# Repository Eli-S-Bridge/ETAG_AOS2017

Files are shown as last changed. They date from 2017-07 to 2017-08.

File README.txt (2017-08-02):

ETAG RFID reader Version1
(Distrubted at the American Ornithological Society Meeting, Lansing, MI, August 2017.

This repository contains:
  1) Eagle design files for the circuit board
  2) A board reference for using the Arduino app with the circuit board.
  3) Arduino code to install on the circuit board

SOFTWARE:

See the setup manual.

HARDWARE:

You can power the board from your USB port or use a 5V battery. 6V batteries seem to work OK too. We’ve tested 4AA batteries in series (which give ~6V). You can power the reader from the USB port or the push-in connectors. Check the + and - labels on the board before connecting the battery leads. The large switch on the circuit board alternates between power sources. If you have both USB and a battery connected, you will not really be able to turn the device off (but you can always use the reset button).

Antenna coils should have inductance of approximately 1.3 milliHenries. You can make the coils yourself by wrapping magnet wire around a form and measuring the inductance until you get it right. Don’t make them bigger than 15cm in diameter or they won’t work very well. You can also buy 1.25mH antennas that work pretty well here:

https://store.qkits.com/rfid/125khz-antenna-for-rfid-controllers-51-5mm.html

Tags need to work at 125kHz and follow the EM4100 communication protocol. Biomark tags generally follow the ISO11784/5 communication protocol will not work. Our favorite tag suppliers are www.cyntag.com (for PITtag style tags) and ibtechnology.co.uk (for RFID leg bands - look for “avian products”)

OTHER RESOURCES:

YouTube video demonstration: https://www.youtube.com/watch?v=-Nv7rSirzx8

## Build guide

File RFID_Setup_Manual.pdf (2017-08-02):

# Table of Contents

1 Introduction | 1
2 Software Installation | 2

1

# Chapter 1

# Introduction

This is the ETAG RFID reader Version1 (Distrubted at the American Ornithological Society Meeting, Lansing, MI, August 2017) guide to set up the software and hardware. This guide will give directions to obtain the Eagle design files for the circuit board, Arduino software, Arduino circuit board code, and an introduction to upload the code to the board for use.

1

# Chapter 2

# Software Installation

This section will direct to download the Ardunio software, RFID code, and RFID data files that are necessary to make the RFID board operational and enable changes to RFID code. This guide will begin by obtaining and installing the Ardunio software then downloading RFID code and data files. The RFID code and data files must be placed in certain Arduno’s directory, this will be further explained in detail.

## 2.1 Ardunio Software

First, go to the Ardunio website to obtain the installer by using the following

link as provided, https://www.arduino.cc/en/Main/Software. The website should appears as Figure 2.1. Click on ”Windows Installer” that is located on the mid-right side of the website. This will redirect you to the next page,

2

Ardunio’s donation page, click ”JUST DOWNLOAD” as shown in Figure 2.2 to begin downloading the executable file.

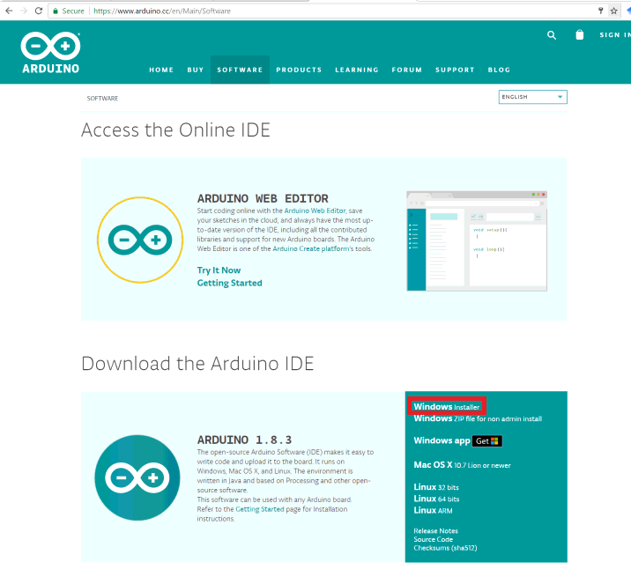
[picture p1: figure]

Figure 2.1: The Arduino Software page to access the correct Ardunino version for your computer. Windows computer should click on ”Windows Installer” to proceeding towards obtaining the Arduino software.

3

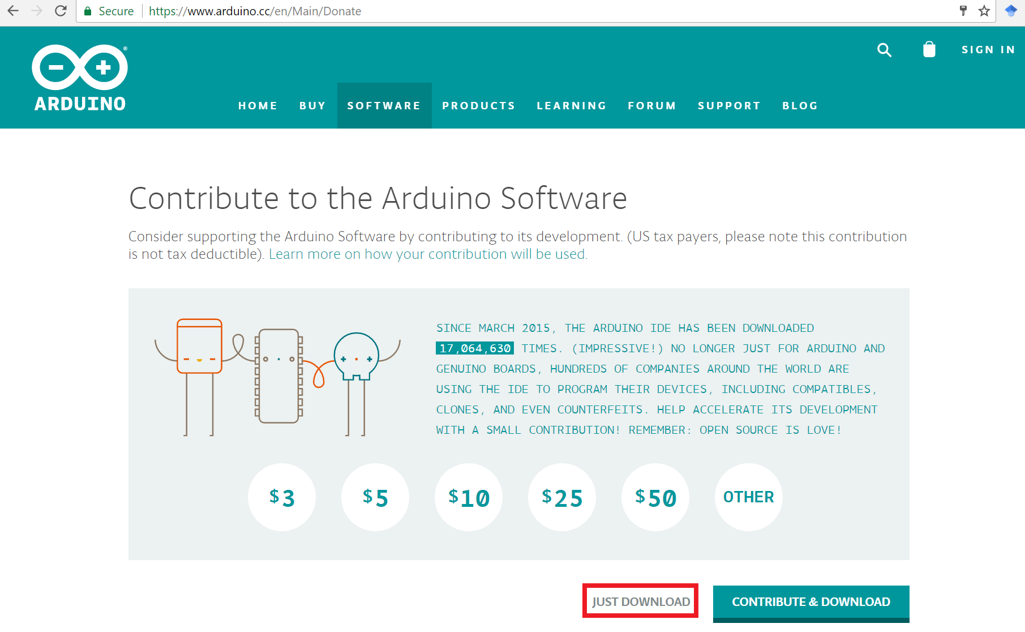
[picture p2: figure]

Figure 2.2: The redirected donation page after clicking ”Windows Installer”. Click on ”JUST DOWNLOAD” to begin downloading the executable file.

4

Locate and double click on the executable file, this will prompt the installer to begin. The initial installer’s title is Arduino Setup: License Agreement window. Read the terms and agreement then click ”I Agree” to begin the installation as shown in Figure 2.3. The installer’s title changes to Arduino Setup: Installation Options, as shown in Figure 2.4, click ”Next”.

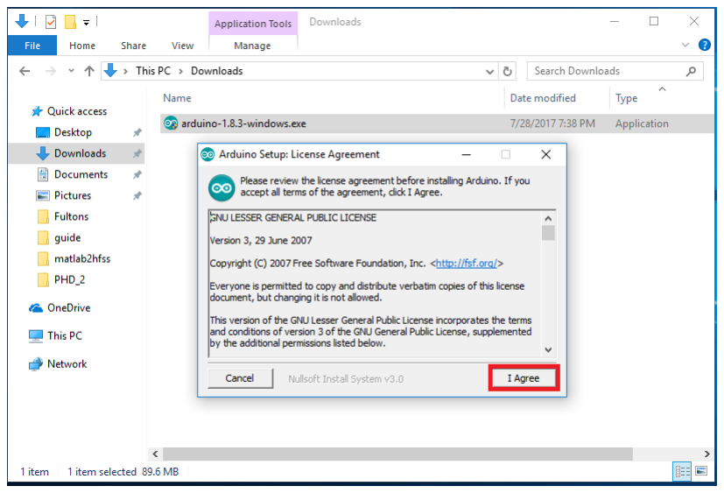
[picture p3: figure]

Figure 2.3: Installer window, displaying the terms and agreements. Click ”I Agree” to continue.

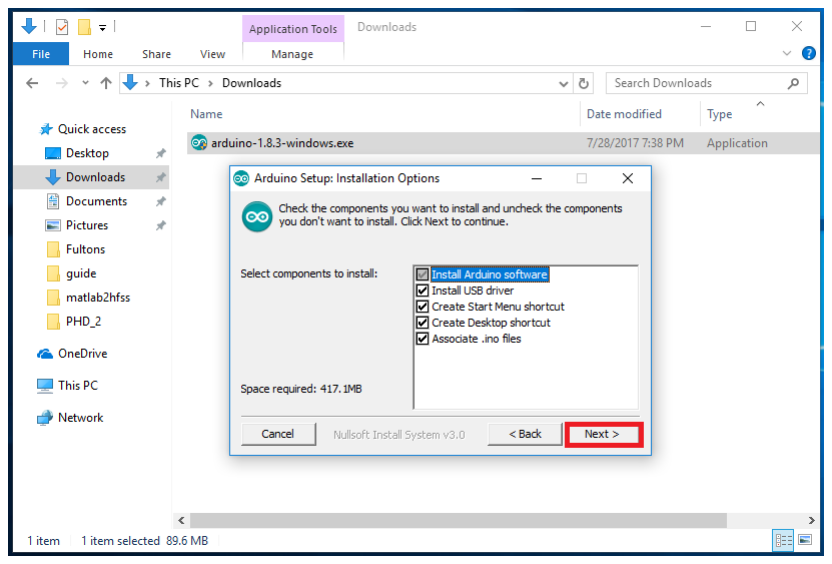
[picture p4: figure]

Figure 2.4: Installer options, click ”Next” to continue.

5

The installer’s title is change to Arduino Setup: Installation Folder, the Default location to install the software will be automatically set. Install location can be changed by clicking ”Browse...”. Click ”Install” as shown in Figure 2.5 to begin but highly recommend to default location. The window will display a progress bar, once completed it state ”Completed” as shown in Figure 2.6, click ”Close”.

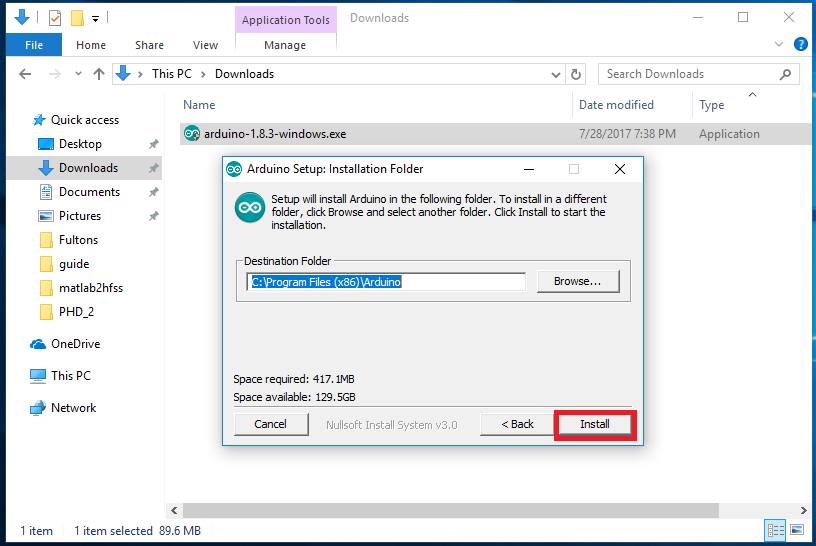
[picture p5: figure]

Figure 2.5: Installer allowing the user to choose destination location for software. Click ”Install” to continue.

6

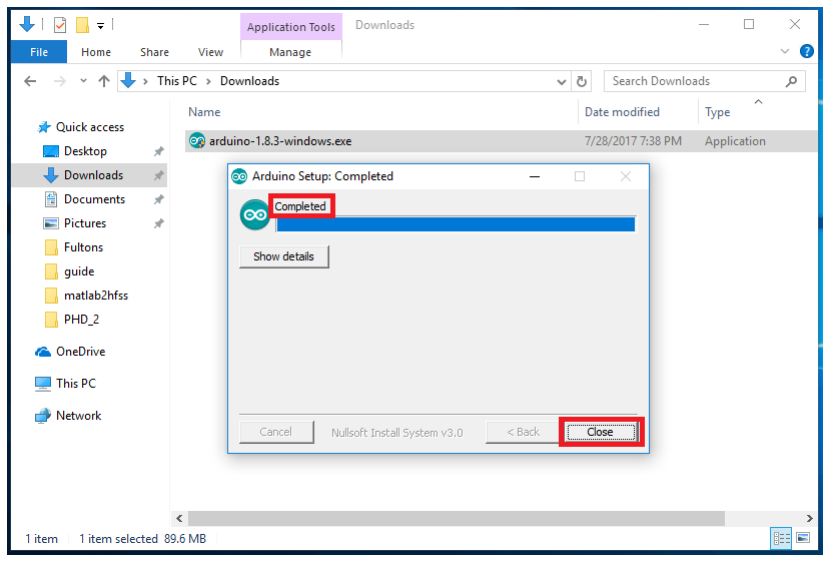
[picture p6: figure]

Figure 2.6: Installer displaying an example of when the installer is completed. click ”Close” to finish.

Accessing the software, click the Windows button on the keyboard prompting the start menu, search ”Arduino”, click on Arduino to run the software. The Arduino software should be successfully installed and running, it will appear as in Figure 2.7

7

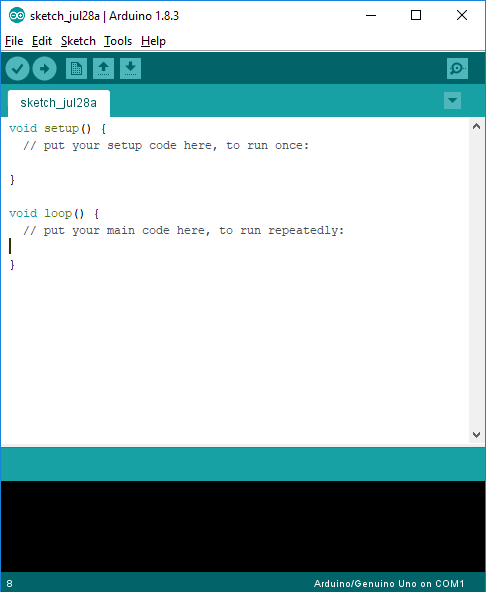
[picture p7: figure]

Figure 2.7: a

8

Next connect your Arduino board to the computer via USB cable, as shown in Figure 2.8. Once the Arduino board is connected to your computer use the switch on the lower right side near the USB port to turn it on, once on the yellow LED light to the side of the switch will light as shown in Figure 2.8(b).

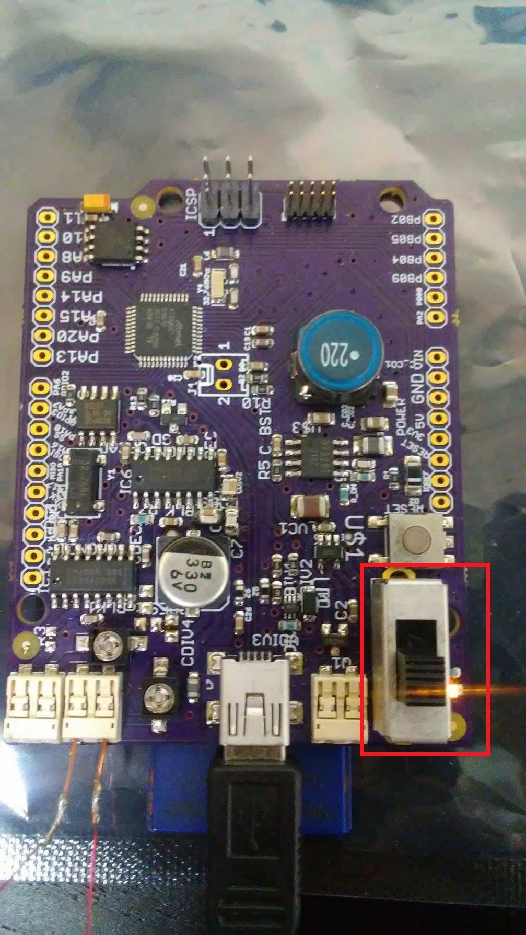
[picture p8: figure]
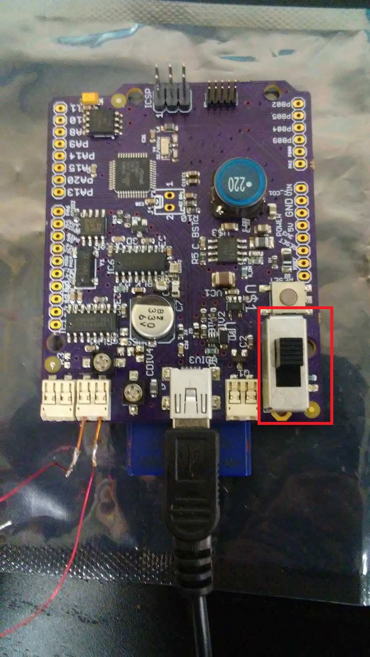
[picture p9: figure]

(a) (b)
Figure 2.8: Use the switch on the bottom right of the Ardunio board near the USB port to turn on the board off and on. A yellow LED to the side of the switch will indicate if the ON or OFF. (a) Yellow LED OFF indicating that Arduino is OFF
(b) Yellow LED ON indicating that Arduino is ON.

9

Once the Arduino board turns on the Arduino software will prompt for updates in the lower left corner as shown in Figure 2.9. Click on this prompt, a new window will open as shown in Figure 2.10. Click on ”Install”, the software will automatically install the files required and will proceed as shown in Figure 2.11, and wait a moment until the window is completed as shown in Figure 2.12.

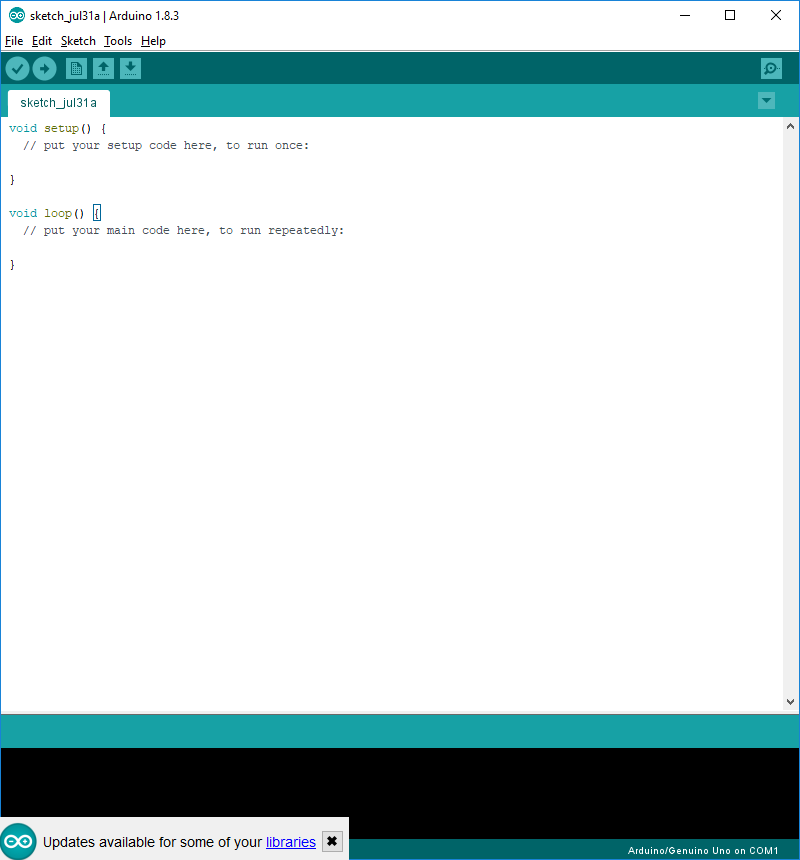
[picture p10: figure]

Figure 2.9: Arduino software prompting for updates after the Arduino board has been turned when connected to the computer. Click on the prompt to install the required updates

10

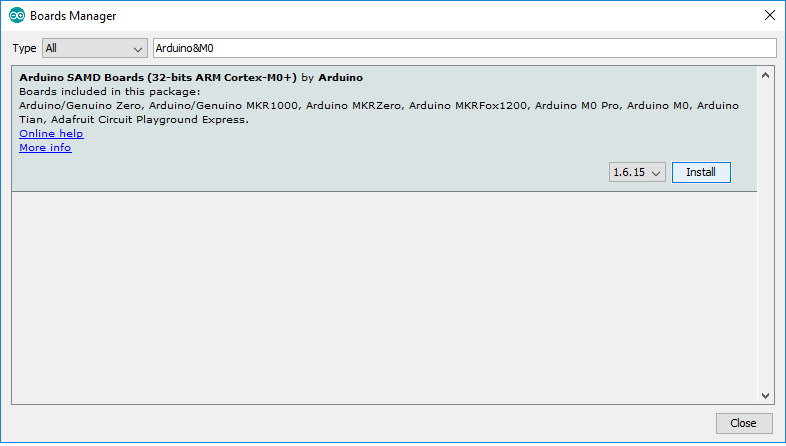
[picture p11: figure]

Figure 2.10: Window prompt to install the required files for Arduino board. Click on the ”Install” button to install required files.

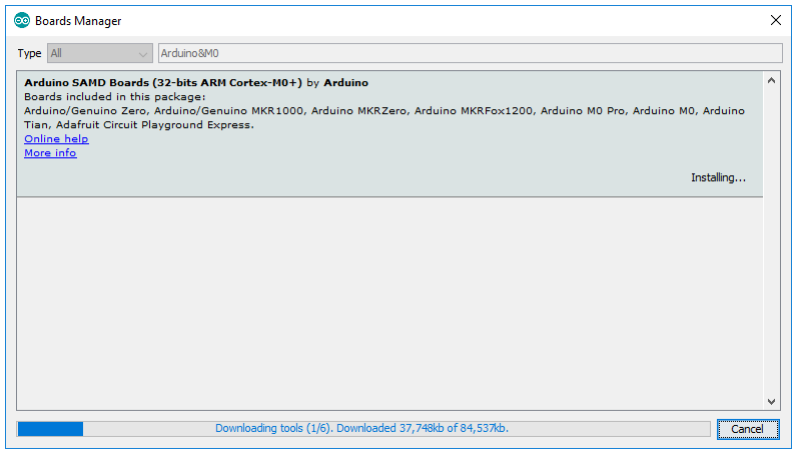
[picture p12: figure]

Figure 2.11: The window prompt in progress during installation. Allow a few moments until it is done installing files.

11

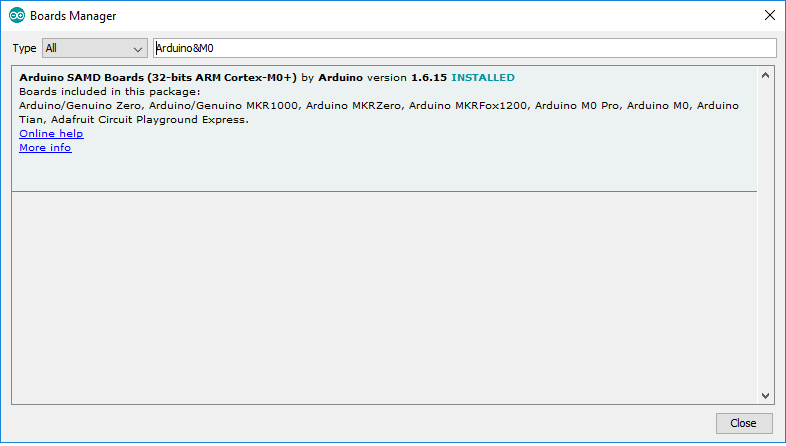
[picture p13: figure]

Figure 2.12: The Arduino software has successfully installed the required files. Click on ”Close”.

Once installation is completed close all Arduino software to prepare for the procedures steps. In the next section there will be directions to obtain our code and files required in utilizing the RFID board.

12

## 2.2 Circuit Board Code and Files

The circuit board code and files can be downloaded from the following url link,

https://github.com/Eli-S-Bridge/ETAG_AOS2017. The web page should appear as in Figure 2.13. Click on ”Clone or download”, a menu box will appear then click ”Download ZIP”. Download the Zip file onto your computer. Once download is complete, locate the Zip file, right click, a window prompt should appear similar to Figure 2.14, and unzip(extract) the files onto your computer.

13

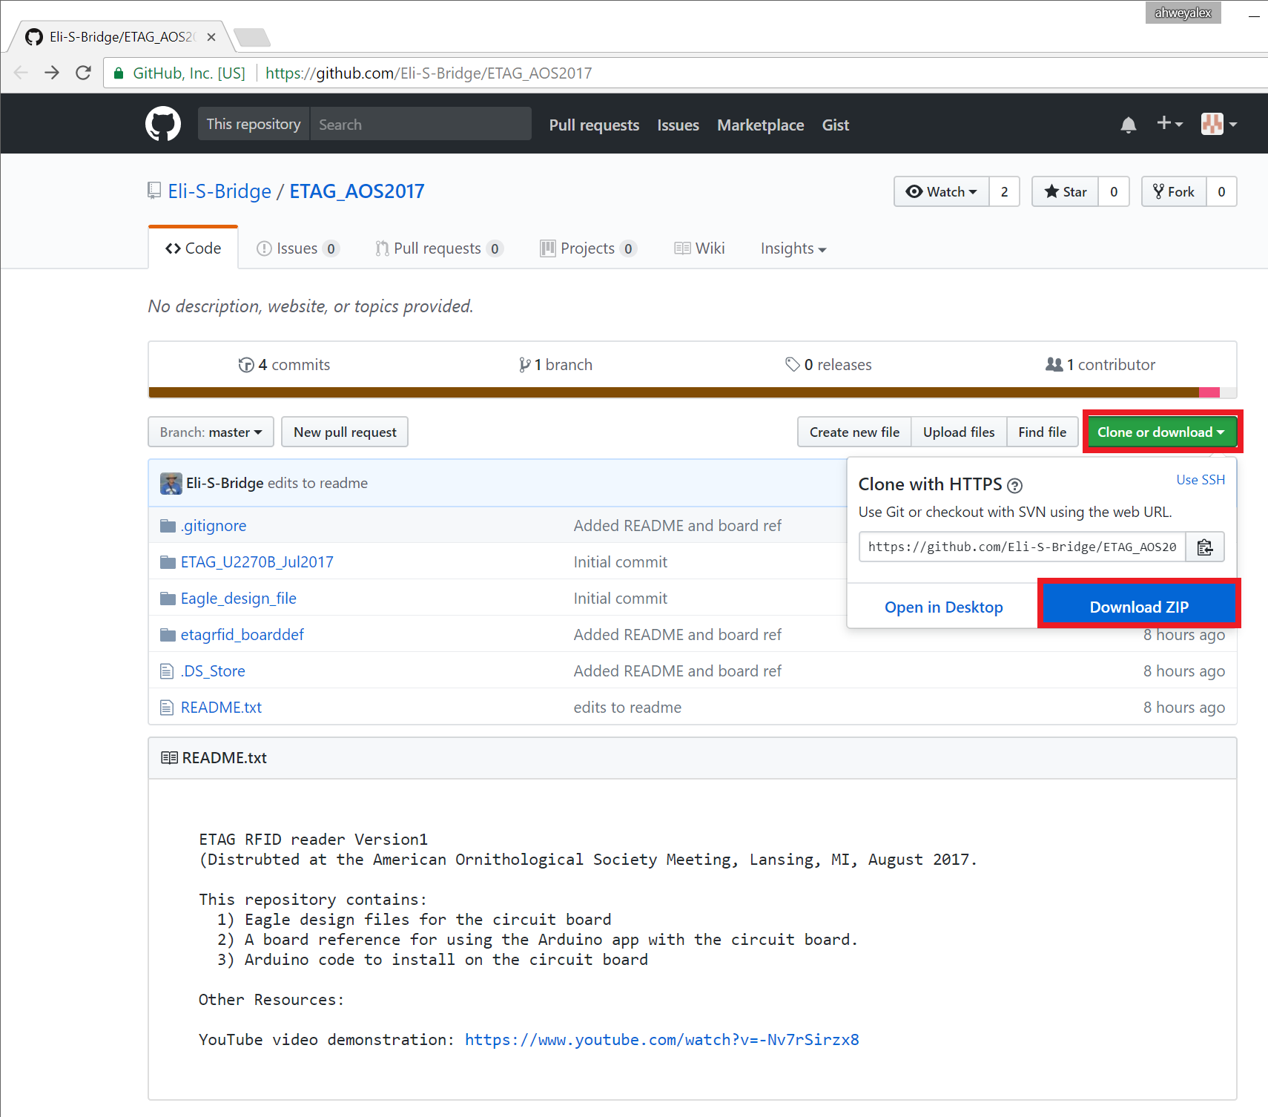
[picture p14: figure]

Figure 2.13: The GitHub web page to download the circuit board code and files. Click on ”Clone or download” then click on ”Download ZIP”.

14

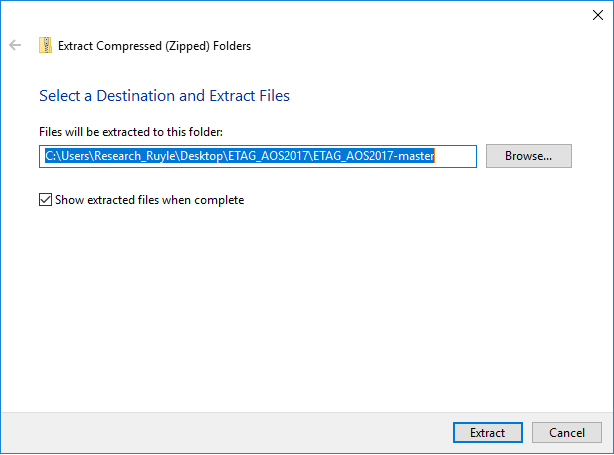
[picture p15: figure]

Figure 2.14: Right click on the zip file that was

15

Open the folder that has just been extracted(unzipped) until you reached a folder that shows the same contents as in Figure 2.15. There are three items(the ”ETAG U2270B” folder,”etagfid” folder, and board.txt file) in this folder that need
to be relocated. Open the folder ”etagfid boarddef” and copy ”board.tx” to

C:\Users\USERNAME\AppData\Local\Arduino15\packages\arduino\ hardware\samd\1.6.15 this will prompt a window, click ”Replace the file
in the destination”, as shown in Figure 2.16. The USERNAME refers to your computer’s user name.

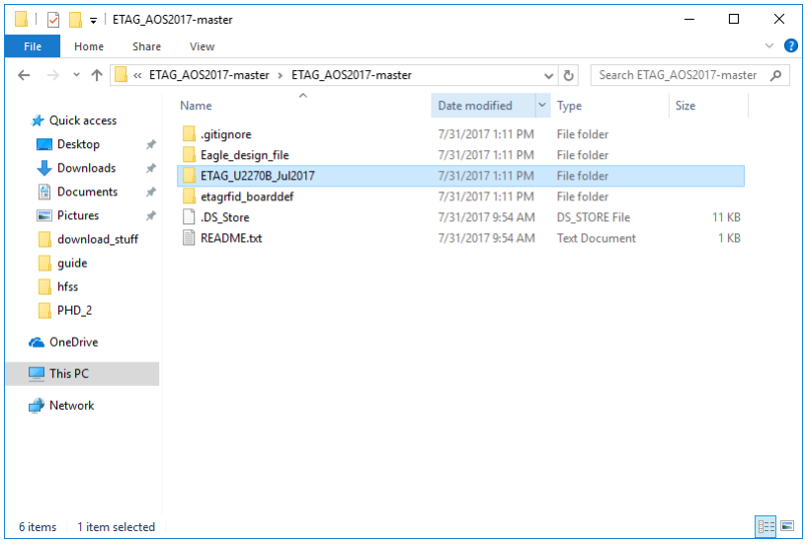
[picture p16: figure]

Figure 2.15: The contents of the unzipped folder.

16

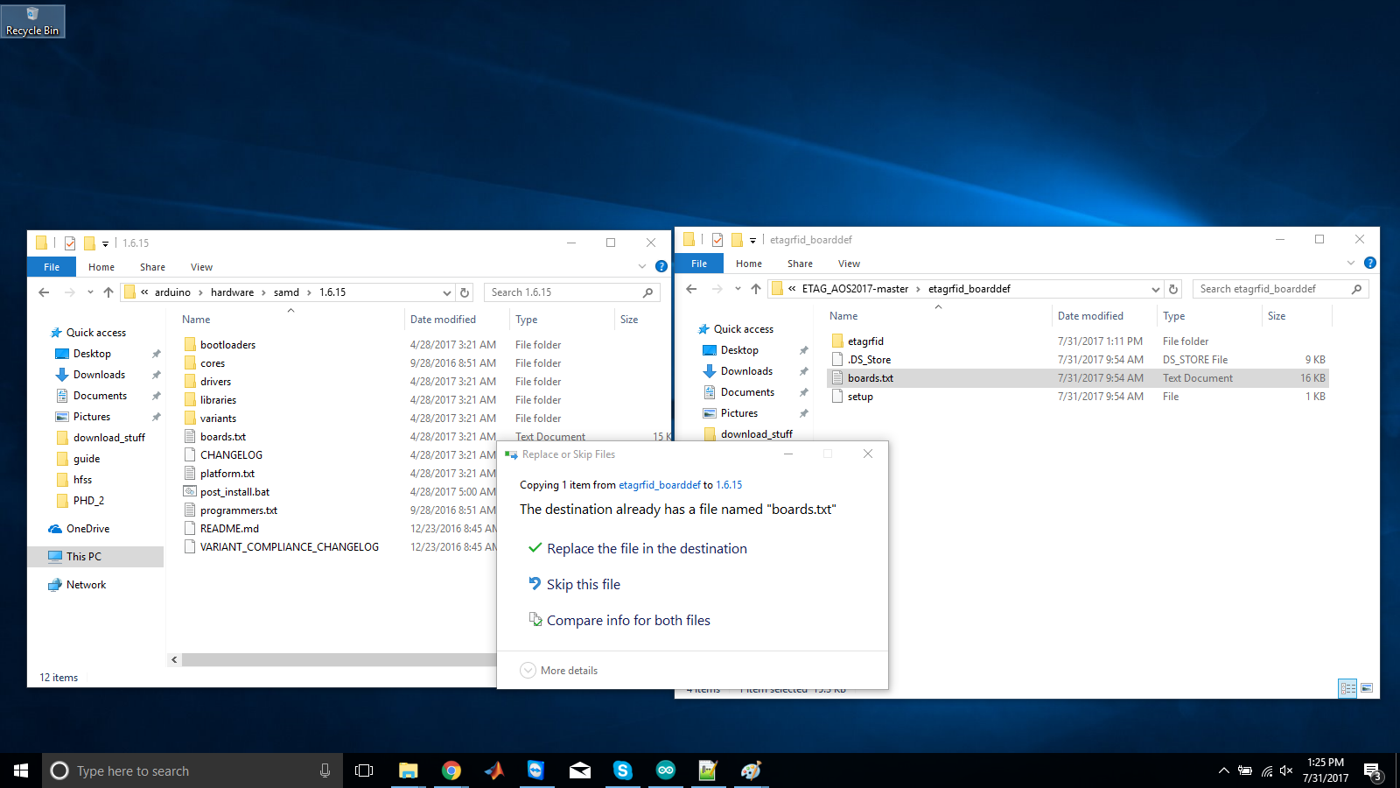
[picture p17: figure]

Figure 2.16: Copying the ”board.txt” file from the unzipped folder into to the path. Click ”Replace the file in the destination”.

17

Next, copy the ”etagfid” folder to the following path,

C:\Users\USERNAME\AppData\Local\Arduino15\packages\arduino\

hardware\samd\1.6.15\variants/ as shown in Figure 2.17.

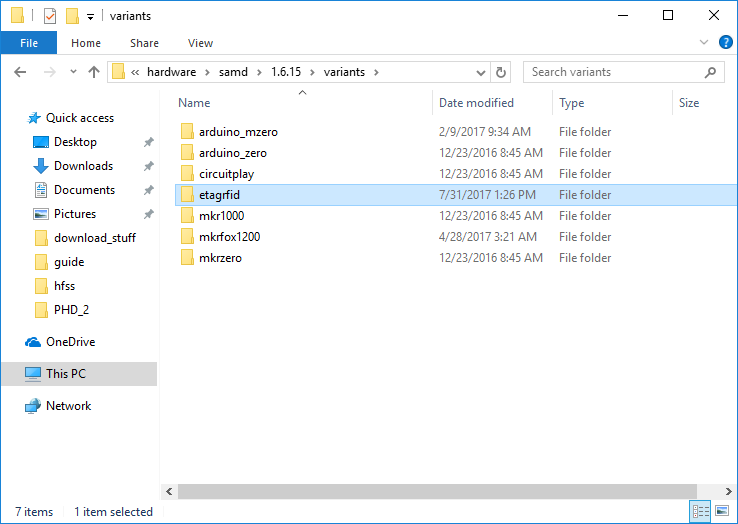
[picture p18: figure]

Figure 2.17

18

Finally, copy the ”ETAG U2270B Jul2017” folder to your Arduino folder located in your Documents folder. This will allow Arduino software easy access to the code.
Open the folder ”ETAG U2270B Jul2017” in your documents, click on ”ETAG U2270B Jul2017.ino” file this will open it in the Arduino software. Then click ”Tools”, scroll down to ”Broad:BOARDNAME”, scroll down and click ”ETAG RFID”. This will ensure compiler to take into account the custom board parameters.
Connect your Arduino board to your computer, turn the board via switch, click on the check mark symbol to verify(compile) the code as shown in Figure 2.18. Once the it completes verifying it will appear as shown Figure 2.19. Then click on the arrow symbol to upload the code into the board. Turn the board off (insert an SD card into the board, if it does not have one) and back on. Next, click on ”Tools”, scroll down to ”Port” and choose ”COM XX”. Finally, Click ”Tools” then scroll down and click on ”Serial Monitor” to prompt the console. Near the tag to the antenna connected to the board to read the tag’s information. The information will be displayed on the console and written onto the SD card.

19

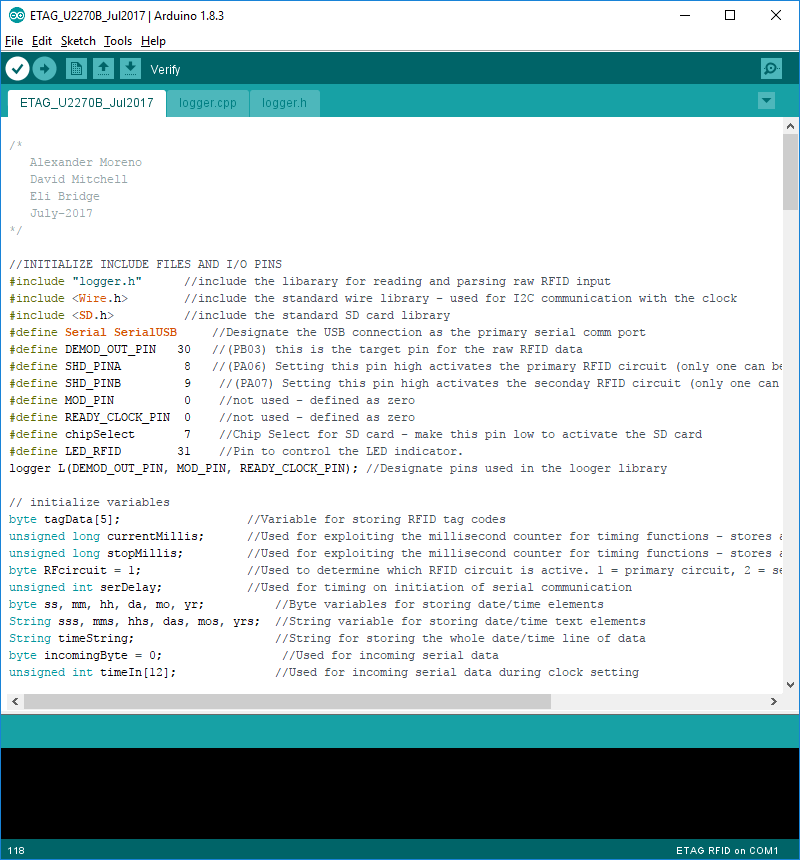
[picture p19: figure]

Figure 2.18: Board code to the RFID.

20

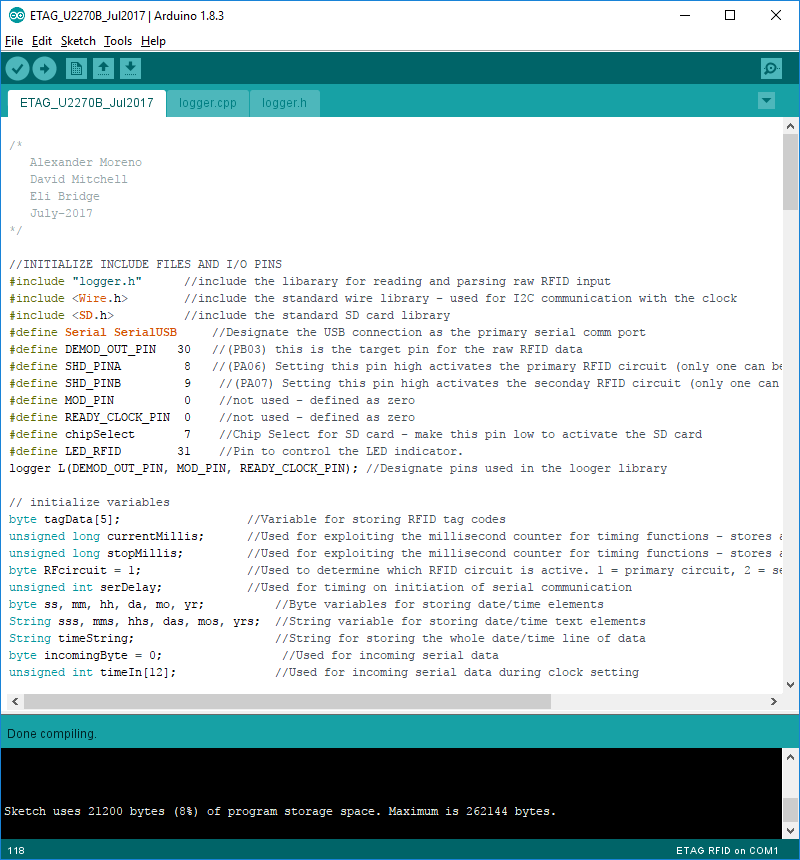
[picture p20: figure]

Figure 2.19: Board code has completed being complied ready to be uploaded to the board.

21

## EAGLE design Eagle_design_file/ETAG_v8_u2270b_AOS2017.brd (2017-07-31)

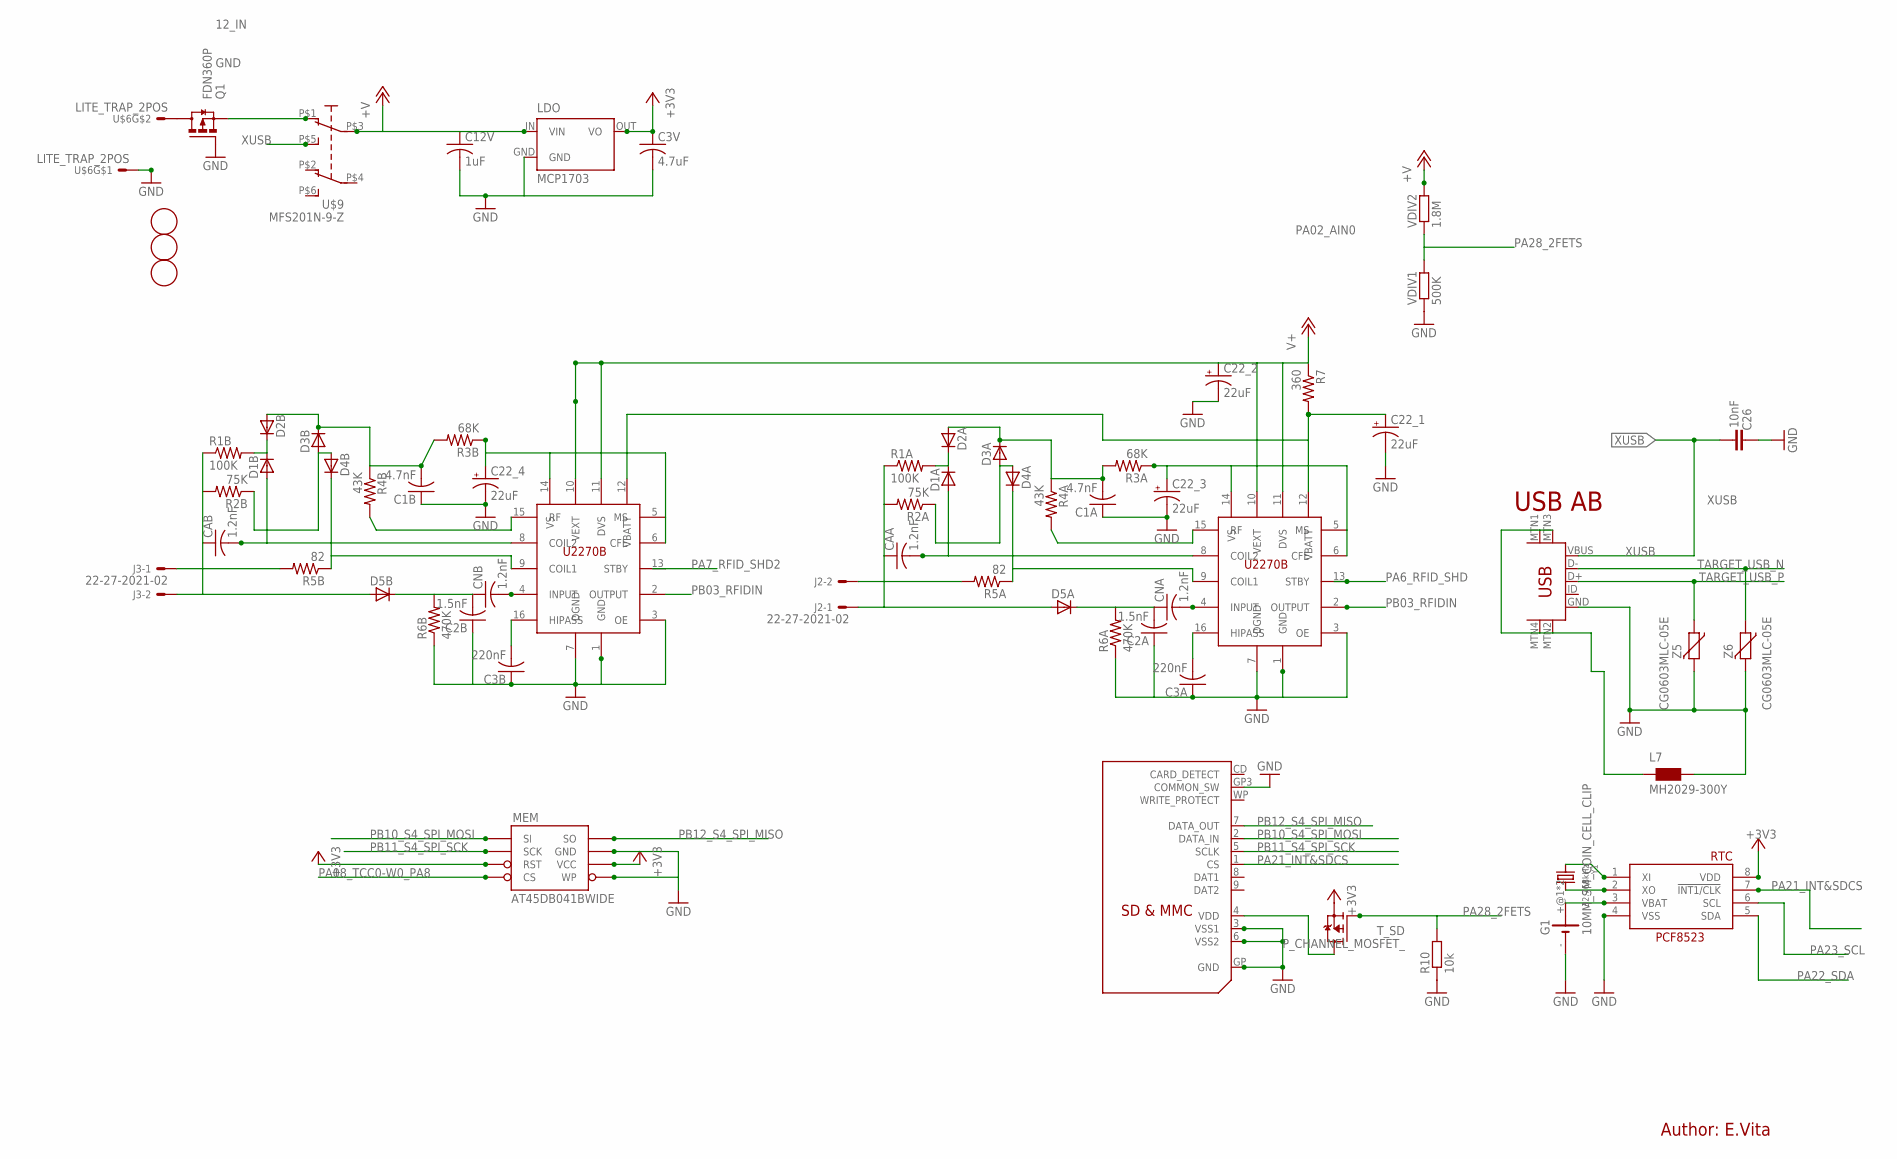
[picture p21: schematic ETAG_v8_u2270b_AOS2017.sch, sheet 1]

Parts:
C1A, C1B: 4.7nF; C0603-ROUND
C2A, C2B: 1.5nF; C0805
C3A, C3B: 220nF; C0603-ROUND
C3V: 4.7uF; C0805
C12V: 1uF; C0805
C22_1, C22_2, C22_3, C22_4: 22uF; 153CLV-0505
C26: 10nF; C0603-ROUND
CAA: 1.2nF; C0805
CAB: 1.2nF; C0805
CNA: 1.2nF; C0805
CNB: 1.2nF; C0805
D1A, D1B, D2A, D2B, D3A, D3B, D4A, D4B, D5A, D5B: D-GLASS_MELF; SOT-23_2PAD
FD1, FD2, FD3: FIDUCIALMOUNT; FIDUCIA-MOUNT
G1: 10MM_SM_COIN_CELL_CLIP
J2, J3: 22-27-2021-02; 6410-02
L7: MH2029-300Y; 0805
LDO: MCP1703; SOT89
MEM: AT45DB041BWIDE; SO08WIDE
Q1: FDN360P; SUPER-SOT3
R1A, R1B: 100K; C0603-ROUND
R2A, R2B: 75K; C0603-ROUND
R3A, R3B: 68K; C0603-ROUND
R4A, R4B: 43K; C0603-ROUND
R5A, R5B: 82; C0603-ROUND
R6A, R6B: 470K; C0603-ROUND
R7: 360; C0603-ROUND
R10: 10k; R0603-ROUND
RF_A: U2270B; SO16
RF_B: U2270B; SO16
RTC: RTC_PCF8523T; SOIC8_150MIL
T_SD: P_CHANNEL_MOSFET_; SOT23
U$4: SDMMC06132; 06132
U$6: LITE_TRAP_2POS; LITE_TRAP_MINI
U$9: MFS201N-9-Z
USB: USB-MINIB-5PIN; USB-MINIB
VDIV1: 500K; R0603-ROUND
VDIV2: 1.8M; R0603-ROUND
Y1: 32.768kHz; CRYSTAL_8X3.8
Z5, Z6: CG0603MLC-05E; CT/CN0603

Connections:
2GND: L7.1, USB.MTN1 (MTN2), USB.MTN2 (MTN3), USB.MTN3 (MTN1), USB.MTN4
12_IN: Q1.3 (D), U$6.P$3, U$6.P$4
+3V3: C3V.1, LDO.OUT (VO), MEM.3 (RST), MEM.6 (VCC), RTC.8 (VDD), T_SD.2 (S); also elsewhere on the board
GND: C1A.1, C1B.1, C2A.1, C2B.1, C3A.1, C3B.1, C3V.2, C12V.2, C22_1.-, C22_2.-, C22_3.-, C22_4.-, C26.2, G1.-, L7.2, LDO.GND, MEM.5 (WP), MEM.7 (GND), Q1.1 (G), R6A.1, R6B.1, R10.1, RF_A.1 (GND), RF_A.3 (OE), RF_A.7 (DGND), RF_B.1 (GND), RF_B.3 (OE), RF_B.7 (DGND), RTC.4 (VSS), U$4.3 (VSS1), U$4.6 (VSS2), U$4.GP (GND), U$4.GP3 (COMMON_SW), U$6.P$1, U$6.P$2, USB.GND, VDIV1.1, Z5.2, Z6.2; also elsewhere on the board
unnamed: RTC.2 (XO), Y1.P$4 (2)
unnamed: RTC.1 (XI), Y1.P$1 (1)
unnamed: C22_1.+, R7.2, RF_A.12 (VBATT), RF_B.12 (VBATT)
unnamed: C3A.2, RF_A.16 (HIPASS)
unnamed: CNA.2, RF_A.4 (INPUT)
unnamed: C2A.2, CNA.1, D5A.P$1 (C), R6A.2
unnamed: C1A.2, D2A.P$2 (A), D3A.P$1 (C), R3A.2, R4A.1
unnamed: J2.2, R5A.2
unnamed: J3.1, R5B.2
unnamed: Q1.2 (S), U$9.P$1 (O)
unnamed: D1A.P$1 (C), D2A.P$1 (C), R1A.2
unnamed: C3B.2, RF_B.16 (HIPASS)
unnamed: D3A.P$2 (A), D4A.P$2 (A), R2A.1
unnamed: CNB.2, RF_B.4 (INPUT)
unnamed: C2B.2, CNB.1, D5B.P$1 (C), R6B.2
unnamed: D4B.P$1 (C), R5B.1, RF_B.9 (COIL1)
unnamed: CAB.2, D1B.P$2 (A), RF_B.8 (COIL2)
unnamed: CAB.1, D5B.P$2 (A), J3.2, R1B.1, R2B.2
unnamed: R4B.2, RF_B.15 (RF)
unnamed: C22_4.+, R3B.1, RF_B.5 (MS), RF_B.6 (CFE), RF_B.14 (VS)
unnamed: D1B.P$1 (C), D2B.P$1 (C), R1B.2
unnamed: D3B.P$2 (A), D4B.P$2 (A), R2B.1
unnamed: C1B.2, D2B.P$2 (A), D3B.P$1 (C), R3B.2, R4B.1
unnamed: D4A.P$1 (C), R5A.1, RF_A.9 (COIL1)
unnamed: CAA.2, D1A.P$2 (A), RF_A.8 (COIL2)
unnamed: CAA.1, D5A.P$2 (A), J2.1, R1A.1, R2A.2
unnamed: R4A.2, RF_A.15 (RF)
unnamed: C22_3.+, R3A.1, RF_A.5 (MS), RF_A.6 (CFE), RF_A.14 (VS)
PA02_AIN0: VDIV1.2, VDIV2.1; also elsewhere on the board
PA6_RFID_SHD: RF_A.13 (STBY); also elsewhere on the board
PA7_RFID_SHD2: RF_B.13 (STBY); also elsewhere on the board
PA08_TCC0-W0_PA8: MEM.4 (CS); also elsewhere on the board
PA21_INT&SDCS: RTC.7 (!INT1/CLK), U$4.1 (CS); also elsewhere on the board
PA22_SDA: RTC.5 (SDA); also elsewhere on the board
PA23_SCL: RTC.6 (SCL); also elsewhere on the board
PA28_2FETS: R10.2, T_SD.1 (G); also elsewhere on the board
PB03_RFIDIN: RF_A.2 (OUTPUT), RF_B.2 (OUTPUT); also elsewhere on the board
PB10_S4_SPI_MOSI: MEM.1 (SI), U$4.2 (DATA_IN); also elsewhere on the board
PB11_S4_SPI_SCK: MEM.2 (SCK), U$4.5 (SCLK); also elsewhere on the board
PB12_S4_SPI_MISO: MEM.8 (SO), U$4.7 (DATA_OUT); also elsewhere on the board
TARGET_USB_N: USB.D-, Z6.1; also elsewhere on the board
TARGET_USB_P: USB.D+, Z5.1; also elsewhere on the board
VBAT1: G1.+@1 (+), G1.+@2 (+), RTC.3 (VBAT)
VDD: T_SD.3 (D), U$4.4 (VDD)
V_IN: C12V.1, C22_2.+, LDO.IN (VIN), R7.1, RF_A.10 (VEXT), RF_A.11 (DVS), RF_B.10 (VEXT), RF_B.11 (DVS), U$9.P$3, VDIV2.2; also elsewhere on the board
XUSB: C26.1, U$9.P$5 (S), USB.VBUS

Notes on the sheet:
USB AB
Author: E.Vita

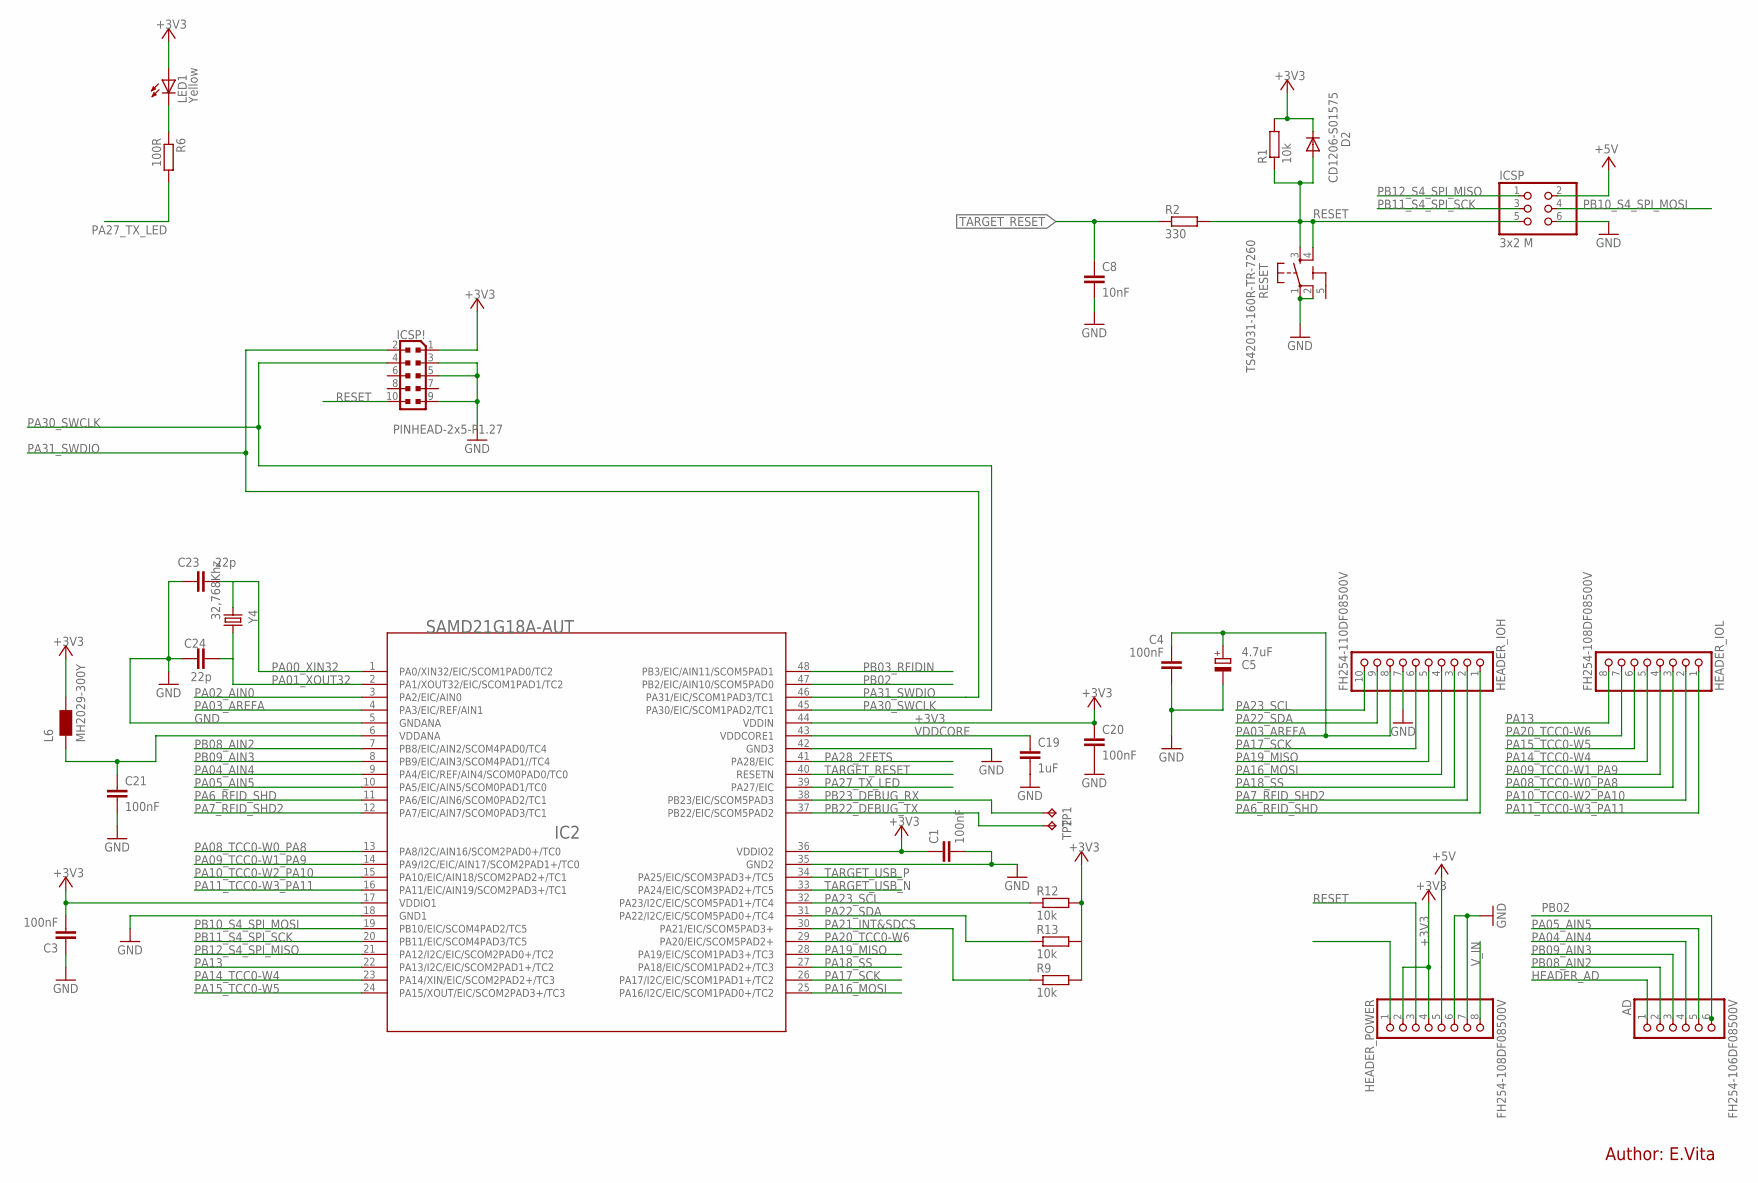
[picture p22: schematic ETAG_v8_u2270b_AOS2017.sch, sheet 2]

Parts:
AD: FH254-106DF08500V; 1X06
C1, C3, C4, C20, C21: 100nF; C0603-ROUND
C5: 4.7uF; SMC_A
C8: 10nF; C0603-ROUND
C19: 1uF; C0603-ROUND
C23, C24: 22p; C0603-ROUND
D2: CD1206-S01575; MINIMELF
HEADER_IOH: FH254-110DF08500V; 1X10
HEADER_IOL: FH254-108DF08500V; 1X08
HEADER_POWER: FH254-108DF08500V; 1X08
IC2: SAMD21G18A-AUT; TQFP48-7X7
ICSP: 3x2 M; 2X03
ICSP!: PINHEAD-2x5-P1.27; PINHEAD_2X05_127
L6: MH2029-300Y; 0805
LED1: Yellow; CHIPLED_0805
R1, R9, R12, R13: 10k; R0603-ROUND
R2: 330; R0603-ROUND
R6: 100R; R0603-ROUND
RESET: TS42031-160R-TR-7260; TS42
TP1, TP2: TPTP15R; TP15R
Y4: 32,768Khz; RESONATOR_EPSON_FC_145

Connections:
5-GND: RESET.5 (5-GND)
+3V3: C1.1, C3.2, C20.1, D2.C, HEADER_POWER.2, HEADER_POWER.4, IC2.17 (VDDIO1), IC2.36 (VDDIO2), IC2.44 (VDDIN), ICSP!.1, L6.2, LED1.A, R1.2, R9.2, R12.2, R13.2; also elsewhere on the board
+5V: HEADER_POWER.5, ICSP.2
GND: C1.2, C3.1, C4.2, C5.-, C8.2, C19.2, C20.2, C21.2, C23.1, C24.1, HEADER_IOH.7, HEADER_POWER.6, HEADER_POWER.7, IC2.5 (GNDANA), IC2.18 (GND1), IC2.35 (GND2), IC2.42 (GND3), ICSP.6, ICSP!.3, ICSP!.5, ICSP!.9, RESET.1, RESET.2; also elsewhere on the board
HEADER_AD: AD.1
unnamed: LED1.C, R6.1
unnamed: C21.1, IC2.6 (VDDANA), L6.1
PA00_XIN32: C23.2, IC2.1 (PA0/XIN32/EIC/SCOM1PAD0/TC2), Y4.P$1 (1)
PA01_XOUT32: C24.2, IC2.2 (PA1/XOUT32/EIC/SCOM1PAD1/TC2), Y4.P$2 (2)
PA02_AIN0: IC2.3 (PA2/EIC/AIN0); also elsewhere on the board
PA03_AREFA: C4.1, C5.+, HEADER_IOH.8, IC2.4 (PA3/EIC/REF/AIN1)
PA04_AIN4: AD.4, IC2.9 (PA4/EIC/REF/AIN4/SCOM0PAD0/TC0)
PA05_AIN5: AD.5, IC2.10 (PA5/EIC/AIN5/SCOM0PAD1/TC0)
PA6_RFID_SHD: HEADER_IOH.1, IC2.11 (PA6/EIC/AIN6/SCOM0PAD2/TC1); also elsewhere on the board
PA7_RFID_SHD2: HEADER_IOH.2, IC2.12 (PA7/EIC/AIN7/SCOM0PAD3/TC1); also elsewhere on the board
PA08_TCC0-W0_PA8: HEADER_IOL.3, IC2.13 (PA8/I2C/AIN16/SCOM2PAD0+/TC0); also elsewhere on the board
PA09_TCC0-W1_PA9: HEADER_IOL.4, IC2.14 (PA9/I2C/EIC/AIN17/SCOM2PAD1+/TC0)
PA10_TCC0-W2_PA10: HEADER_IOL.2, IC2.15 (PA10/EIC/AIN18/SCOM2PAD2+/TC1)
PA11_TCC0-W3_PA11: HEADER_IOL.1, IC2.16 (PA11/EIC/AIN19/SCOM2PAD3+/TC1)
PA13: HEADER_IOL.8, IC2.22 (PA13/I2C/EIC/SCOM2PAD1+/TC2)
PA14_TCC0-W4: HEADER_IOL.5, IC2.23 (PA14/XIN/EIC/SCOM2PAD2+/TC3)
PA15_TCC0-W5: HEADER_IOL.6, IC2.24 (PA15/XOUT/EIC/SCOM2PAD3+/TC3)
PA16_MOSI: HEADER_IOH.4, IC2.25 (PA16/I2C/EIC/SCOM1PAD0+/TC2)
PA17_SCK: HEADER_IOH.6, IC2.26 (PA17/I2C/EIC/SCOM1PAD1+/TC2)
PA18_SS: HEADER_IOH.3, IC2.27 (PA18/EIC/SCOM1PAD2+/TC3)
PA19_MISO: HEADER_IOH.5, IC2.28 (PA19/EIC/SCOM1PAD3+/TC3)
PA20_TCC0-W6: HEADER_IOL.7, IC2.29 (PA20/EIC/SCOM5PAD2+)
PA21_INT&SDCS: IC2.30 (PA21/EIC/SCOM5PAD3+), R9.1; also elsewhere on the board
PA22_SDA: HEADER_IOH.9, IC2.31 (PA22/I2C/EIC/SCOM5PAD0+/TC4), R13.1; also elsewhere on the board
PA23_SCL: HEADER_IOH.10, IC2.32 (PA23/I2C/EIC/SCOM5PAD1+/TC4), R12.1; also elsewhere on the board
PA27_TX_LED: IC2.39 (PA27/EIC), R6.2
PA28_2FETS: IC2.41 (PA28/EIC); also elsewhere on the board
PA30_SWCLK: IC2.45 (PA30/EIC/SCOM1PAD2/TC1), ICSP!.4
PA31_SWDIO: IC2.46 (PA31/EIC/SCOM1PAD3/TC1), ICSP!.2
PB02: AD.6, IC2.47 (PB2/EIC/AIN10/SCOM5PAD0)
PB03_RFIDIN: IC2.48 (PB3/EIC/AIN11/SCOM5PAD1); also elsewhere on the board
PB08_AIN2: AD.2, IC2.7 (PB8/EIC/AIN2/SCOM4PAD0/TC4)
PB09_AIN3: AD.3, IC2.8 (PB9/EIC/AIN3/SCOM4PAD1//TC4)
PB10_S4_SPI_MOSI: IC2.19 (PB10/EIC/SCOM4PAD2/TC5), ICSP.4; also elsewhere on the board
PB11_S4_SPI_SCK: IC2.20 (PB11/EIC/SCOM4PAD3/TC5), ICSP.3; also elsewhere on the board
PB12_S4_SPI_MISO: IC2.21 (PA12/I2C/EIC/SCOM2PAD0+/TC2), ICSP.1; also elsewhere on the board
PB22_DEBUG_TX: IC2.37 (PB22/EIC/SCOM5PAD2), TP2.TP
PB23_DEBUG_RX: IC2.38 (PB23/EIC/SCOM5PAD3), TP1.TP
RESET: D2.A, HEADER_POWER.3, ICSP.5, ICSP!.10, R1.1, R2.2, RESET.3, RESET.4
TARGET_RESET: C8.1, IC2.40 (RESETN), R2.1
TARGET_USB_N: IC2.33 (PA24/EIC/SCOM3PAD2+/TC5); also elsewhere on the board
TARGET_USB_P: IC2.34 (PA25/EIC/SCOM3PAD3+/TC5); also elsewhere on the board
VDDCORE: C19.1, IC2.43 (VDDCORE1)
V_IN: HEADER_POWER.8; also elsewhere on the board

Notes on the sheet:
Author: E.Vita

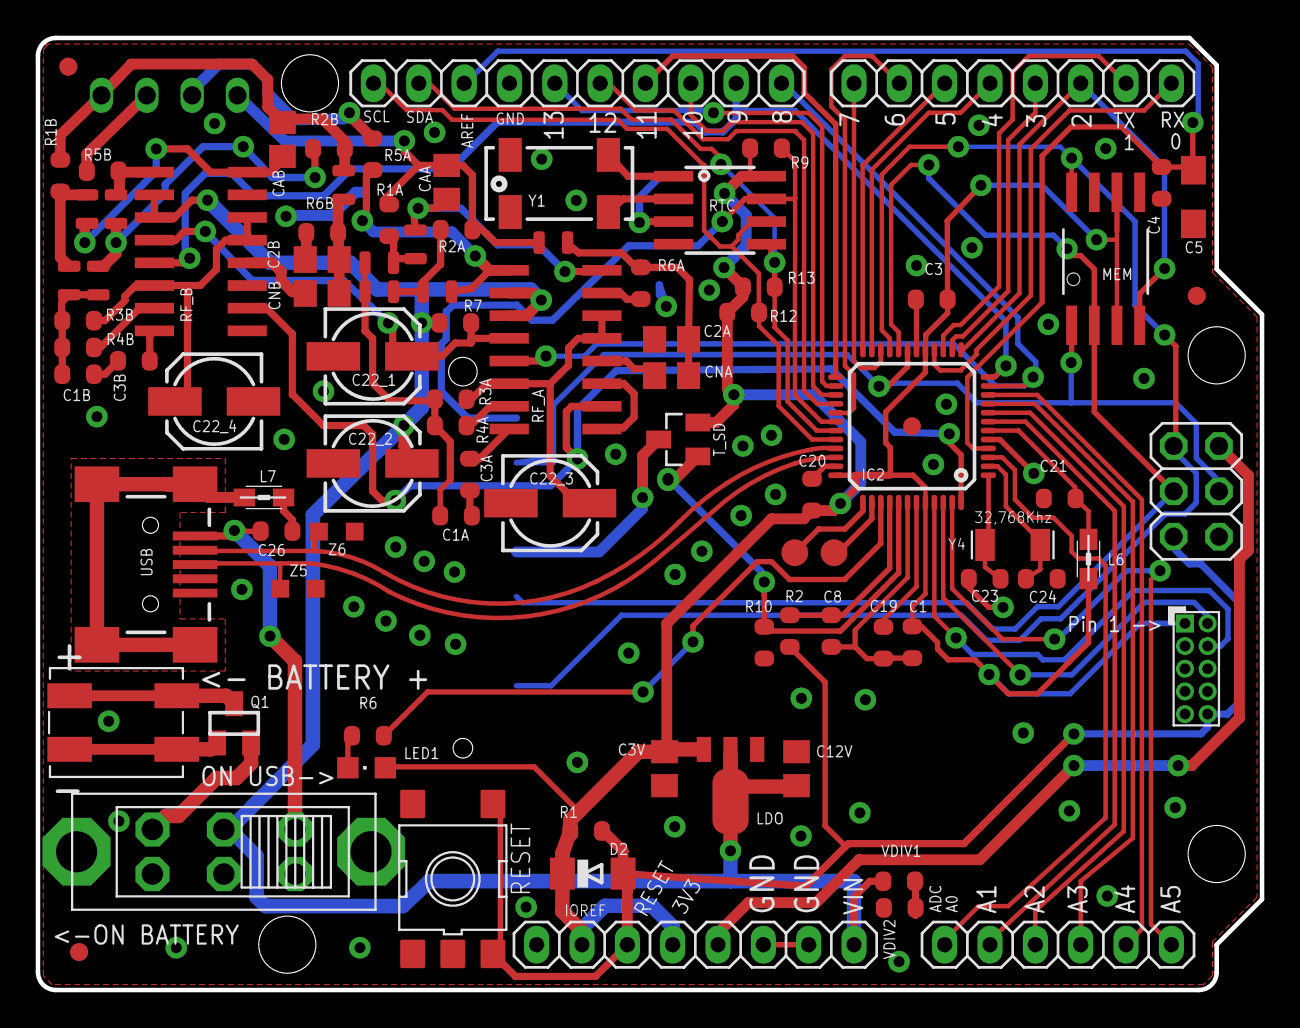
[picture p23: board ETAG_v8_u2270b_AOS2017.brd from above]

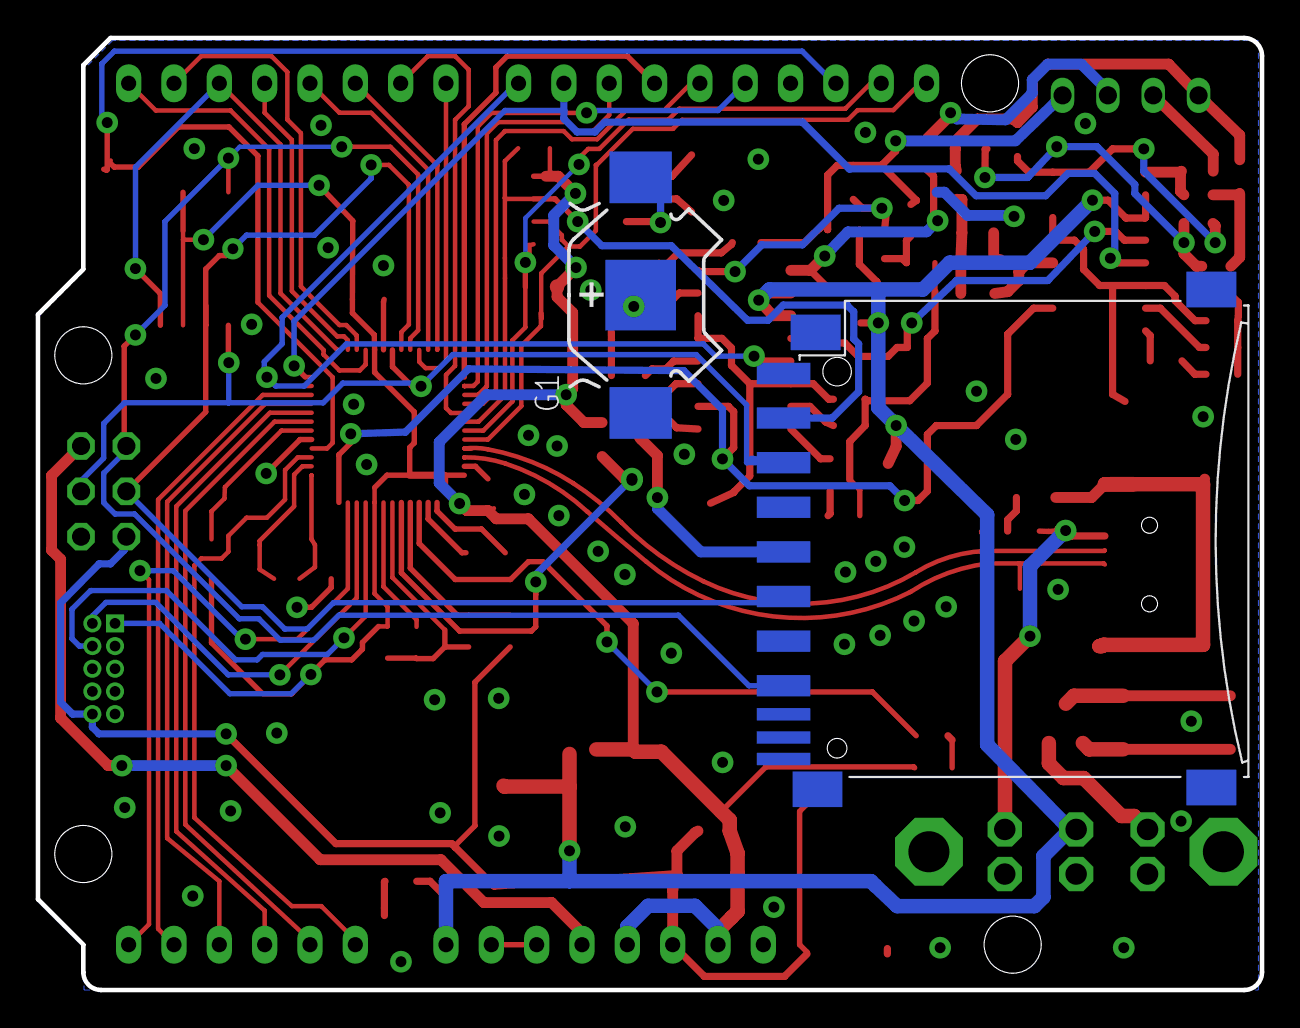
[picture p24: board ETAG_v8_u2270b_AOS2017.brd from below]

Board: 4 copper layers, 68.6 x 53.3 mm, 94 parts (2 on the bottom side), 80 nets.

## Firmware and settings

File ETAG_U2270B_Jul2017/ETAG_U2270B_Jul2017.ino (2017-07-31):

/*
 Data logging sketch for the ETAG RFID Reader
 Version 1. Distributed at AOS2017

 Code by:
   Alexander Moreno
   David Mitchell
   Eli Bridge
   July-2017

 Licenced in the public domain

 REQUIREMENTS:
  The files "logger.cpp" and "logger.h" must be in the same folder as this sketch file
  Power supply for the board should come from the USB cable or a 5V battery or DV power source.
  A 3.3V CR1025 coin battery should be installed on the back side of the board to maintain the date
      and time when the board is disconnected from a primary power source.
*/

//INITIALIZE INCLUDE FILES AND I/O PINS
#include "logger.h"      //include the library for reading and parsing raw RFID input
#include <Wire.h>        //include the standard wire library - used for I2C communication with the clock
#include <SD.h>          //include the standard SD card library
#define Serial SerialUSB     //Designate the USB connection as the primary serial comm port
#define DEMOD_OUT_PIN   30   //(PB03) this is the target pin for the raw RFID data
#define SHD_PINA         8   //(PA06) Setting this pin high activates the primary RFID circuit (only one can be active at a time)
#define SHD_PINB         9    //(PA07) Setting this pin high activates the seconday RFID circuit (only one can be active at a time)
#define MOD_PIN          0    //not used - defined as zero
#define READY_CLOCK_PIN  0    //not used - defined as zero
#define chipSelect       7    //Chip Select for SD card - make this pin low to activate the SD card
#define LED_RFID        31    //Pin to control the LED indicator.  
logger L(DEMOD_OUT_PIN, MOD_PIN, READY_CLOCK_PIN); //Designate pins used in the looger library

// initialize variables
byte tagData[5];                  //Variable for storing RFID tag codes
unsigned long currentMillis;      //Used for exploiting the millisecond counter for timing functions - stores a recent result of the millis() function
unsigned long stopMillis;         //Used for exploiting the millisecond counter for timing functions - stores a less recent result of the millis() function
byte RFcircuit = 1;               //Used to determine which RFID circuit is active. 1 = primary circuit, 2 = secondary circuit. 
unsigned int serDelay;            //Used for timing on initiation of serial communication
byte ss, mm, hh, da, mo, yr;          //Byte variables for storing date/time elements
String sss, mms, hhs, das, mos, yrs;  //String variable for storing date/time text elements
String timeString;                    //String for storing the whole date/time line of data
byte incomingByte = 0;                 //Used for incoming serial data
unsigned int timeIn[12];              //Used for incoming serial data during clock setting

//CONSTANTS (SET UP LOGGING PARAMETERS HERE!!)
const unsigned int polltime = 3000;       //How long in milliseconds to poll for tags 
const unsigned int pausetime = 500;       //How long in milliseconds to wait between polling intervals 
const unsigned int readFreq = 200;        //How long to wait after a tag is successfully read.

void setup() {  // This function sets everything up for logging.
  pinMode(SHD_PINA, OUTPUT);     // Make the primary RFID shutdown pin an output.
  digitalWrite(SHD_PINA, LOW);   // turn the primary RFID circuit off (HIGH turns it on)
  pinMode(SHD_PINB, OUTPUT);
  digitalWrite(SHD_PINA, LOW);   // turn the secondary RFID circuit off
  pinMode(LED_RFID, OUTPUT);
  digitalWrite(LED_RFID, HIGH);  // turn the LED off (LOW turns it on)
  initclk();                     // Calls a function to start the clock ticking if it wasn't doing so already

  //Try to initiate a serial connection
  Serial.begin(9600);               //Initiate a serial connection with the given baud rate
  ss = 0;                           //Initialize a variable for counting in the while loop that follows
  while (ss < 5 && !Serial) {       //flash LED 5 times while waiting for serial connection to come online
     delay(500);                    //pause for 0.5 seconds
    digitalWrite(LED_RFID, LOW);    //turn the LED on (LOW turns it on)
    delay(500);                     //pause again
    digitalWrite(LED_RFID, HIGH);   //turn the LED off (HIGH turns it off)
    ss = ss + 1;                    //add to counting variable
  }//end while
  digitalWrite(LED_RFID, HIGH);     // make sure LED is off 
   Serial.println("set clock?  Y or N.");             //Ask if the user wants to set the clock
   serDelay = 0;                                      //If there's no response then just start logging
   while(Serial.available() == 0 && serDelay < 10000) //wait about 10 seconds for a user response
    {
      delay(1);                                     
      serDelay++;
    } 
    if (Serial.available()){           //If there is a response check to see if it is "Y"
      incomingByte = Serial.read();
    } 
    if(incomingByte == 89) {           //"Y" is the ascii character equivalent of 89
      setClk();                        //if the user enters "Y" (89) then call the clock setting function
      }
    
  //Set up the SD card
  Serial.print("Initializing SD card...\n");              //message to user
  if (!SD.begin(chipSelect)) {                            //Initiate the SD card function with the pin that activates the card.
    Serial.println("\nSD card failed, or not present");   //SD card error message
    return;
  }// end check SD
 
  RFcircuit = 1;                              //Indicates that the reader should start with the primary RFID circuit 
  Serial.println("Scanning for tags...\n");   //message to user
} // end setup        

void loop() {  //This is the main function. It loops (repeats) forever.
  if (RFcircuit == 1)               //Determin which RFID circuit to activate
    {digitalWrite(SHD_PINA, HIGH);} //Turn on primary RFID circuit
    else 
    {digitalWrite(SHD_PINB, HIGH);} //Turn on secondary RFID circuit
  
  Serial.print("Scanning RFID circuit "); //Tell the user which circuit it active
  Serial.println(RFcircuit);
    
  //scan for a tag - if a tag is sucesfully scanned, return a 'true' and proceed
  currentMillis = millis();                //To determine how long to poll for tags, first get the current value of the built in millisecond clock on the processor
  stopMillis = currentMillis + polltime;   //next add the value of polltime to the current clock time to determine the desired stop time.
  while(stopMillis > millis()) {           //As long as the stoptime is less than the current millisecond counter, then keep looking for a tag
    if (L.scanForTag(tagData) == true) {   //If a tag gets read, then do all the following stuff (if not it will keep trying until the timer runs out)
      Serial.print("RFID Tag Detected: "); //Print a message stating that a tag was found
      getTime();                           //Call a subroutine function that reads the time from the clock
      
      for (int n = 0; n < 5; n++) {             //loop to send tag data over serial comm one byte at a time
        if (tagData[n] < 10) Serial.print("0"); //send a leading zero if necessary (so "03" does not get shortened to "3")
        Serial.print(tagData[n], HEX);          //Send byte
      }
      Serial.print(" on antenna ");  // add a note about which atenna was used
      Serial.print(RFcircuit);
      Serial.print(" at ");           // add the time the tag was logged and complete the data line
      Serial.println(timeString);
          
      for (unsigned int n = 0; n < readFreq ; n = n + 30) {      //loop to Flash LED and delay reading after getting a tag
           digitalWrite(LED_RFID, LOW);                          //The approximate duration of this loop is determined by the readFreq value
           delay(5);                                             //It determines how long to wait after a successful read before polling for tags again
           digitalWrite(LED_RFID, HIGH);
           delay(25);
          }

      File dataFile = SD.open("datalog.txt", FILE_WRITE);        //Initialize the SD card and open the file "datalog.txt" or create it if it is not there.
      if (dataFile) {                              
        for (int n = 0; n < 5; n++) {               //loop to print out the RFID code to the SD card
          if (tagData[n] < 10) dataFile.print("0"); //add a leading zero if necessary
          dataFile.print(tagData[n], HEX);          //print to the SD card
          }
        dataFile.print(",");                        //comma for data delineation
        dataFile.print(RFcircuit);                  //log which antenna was active
        dataFile.print(",");                        //comma for data delineation
        dataFile.println(timeString);               //log the time
        dataFile.close();                           //close the file
        Serial.println("saved to SD card.");        //serial output message to user
      } // check dataFile is present
      else {
        Serial.println("error opening datalog.txt");  //error message if the "datafile.txt" is not present or cannot be created
      }// end check for file
    } // end ScanForTag
  } //end while

  //The following gets executed when the above while loop times out
    digitalWrite(SHD_PINA, LOW);    //Turn off both RFID circuits
    digitalWrite(SHD_PINB, LOW);    //Turn off both RFID circuits
    delay(pausetime);               //pause between polling attempts  
    if (RFcircuit == 1)             //switch between active RF circuits.
      {RFcircuit = 2;}
      else
      {RFcircuit = 1;}
    //RFcircuit = 1;              //This lines sets the active RF circuit to 1. comment out or delete to use both circuits. Uncomment if you just want to use the primary circuit.
}// end void loop


////The Following are all subroutines called by the code above.//////////////

byte bcdToDec(byte val)  {   // Convert binary coded decimals (from the clock) to normal decimal numbers
  return ( (val/16*10) + (val%16) );
}

byte decToBcd( byte val ) {  // Convert decimal to binary coded decimals for writing to the clock
   return (byte) ((val / 10 * 16) + (val % 10));
}

static uint8_t conv2d(const char* p) { // Convert parts of a string to decimal numbers (not used in this version)
    uint8_t v = 0;
    if ('0' <= *p && *p <= '9')
        v = *p - '0';
    return 10 * v + *++p - '0';
}

void initclk () {                //Start the clock running if it is not already
  Wire.begin();                  //Start up the I2C comm funcitons
  Wire.beginTransmission(0x68);  //Send the clock slave address
  Wire.write(0x0C);              //address for clearing the HT (halt time?) bit
  Wire.write(0x3F);              //HT is bit 6 so 00111111 clears it.
  Wire.endTransmission();        //End the I2C transmission
}

void setClk() {                          //Function to set the clock)
  Serial.println("Enter mmddyyhhmmss");  //Ask for user input
   while(Serial.available() == 0) {}     //wait for 12 characters to accumulate
   for (int n = 0; n < 13; n++) {        //loop to read all the data from the serial buffer once it is ready
      timeIn[n] = Serial.read();         //Read the characters from the buffer into an array of 12 bytes one at a time
   }
    while(Serial.available())            //Clear the buffer, in case there were extra characters
      {Serial.read();}

   mo = ((timeIn[0]-48)*10 + (timeIn[1]-48));    //Convert two ascii characters into a single decimal number
   da = ((timeIn[2]-48)*10 + (timeIn[3]-48));    //Convert two ascii characters into a single decimal number
   yr = ((timeIn[4]-48)*10 + (timeIn[5]-48));    //Convert two ascii characters into a single decimal number
   hh = ((timeIn[6]-48)*10 + (timeIn[7]-48));    //Convert two ascii characters into a single decimal number       
   mm = ((timeIn[8]-48)*10 + (timeIn[9]-48));    //Convert two ascii characters into a single decimal number
   ss = ((timeIn[10]-48)*10 + (timeIn[11]-48));  //Convert two ascii characters into a single decimal number

  //Write the new time to the clock usind I2C protocols implemented in the Wire library
  initclk();                    //Make sure the clock is running
  Wire.beginTransmission(0x68); //Begin I2C communication using the I2C address for the clock
  Wire.write(0x00);             //starting register - register 0
  Wire.write(0x00);             //write to register 0 - psecs (100ths of a second - can only be set to zero
  Wire.write(decToBcd(ss));     //write to register 1 - seconds
  Wire.write(decToBcd(mm));     //write to register 2 - minutes
  Wire.write(decToBcd(hh));     //write to register 3 - hours 
  Wire.write(0x01);             //write to register 4 - day of the week (we don't care about this)
  Wire.write(decToBcd(da));     //write to register 5 - day of month
  Wire.write(decToBcd(mo));     //write to register 6 - month
  Wire.write(decToBcd(yr));     //write to register 7 - year
  Wire.endTransmission();
    
  getTime();                      //Read from the time registers you just set 
  Serial.print("Clock set to ");  //message confirming clock time
  Serial.println(timeString);

  //When the clock is set (more specifically when Serial.read is used) the RFID circuit fails)
  //I don't know why this happens
  //Only solution seems to be to restart the device. 
  //So the following messages inform the user to restart the device.
  Serial.print("Restart reader to log data."); 
  while(1){}                                     //Endless while loop. Program ends here. User must restart.
}

void getTime() {  //Read in the time from the clock registers
  Wire.beginTransmission(0x68);  //I2C address for the clock
  Wire.write(0x01);              //start to read from register 1 (seconds)
  Wire.endTransmission();
  Wire.requestFrom(0x68, 7);     //Request seven bytes from seven consecutive registers on the clock.
  if (Wire.available()) {
    ss = Wire.read(); //second
    mm = Wire.read(); //minute
    hh = Wire.read(); //hour
    da = Wire.read(); //day of week, which we don't care about. this byte gets overwritten in next line
    da = Wire.read(); //day of month
    mo = Wire.read(); //month
    yr = Wire.read(); //year
  }
  sss = ss < 10 ? "0"+String(bcdToDec(ss), DEC) : String(bcdToDec(ss), DEC); //These lines convert decimals to characters to build a
  mms = mm < 10 ? "0"+String(bcdToDec(mm), DEC) : String(bcdToDec(mm), DEC); //string with the date and time 
  hhs = hh < 10 ? "0"+String(bcdToDec(hh), DEC) : String(bcdToDec(hh), DEC); //They use a shorthand if/then/else statement to add 
  das = da < 10 ? "0"+String(bcdToDec(da), DEC) : String(bcdToDec(da), DEC); //leading zeros if necessary
  mos = mo < 10 ? "0"+String(bcdToDec(mo), DEC) : String(bcdToDec(mo), DEC);
  yrs = yr < 10 ? "0"+String(bcdToDec(yr), DEC) : String(bcdToDec(yr), DEC);
  timeString = mos+"/"+das+"/"+yrs+" "+hhs+":"+mms+":"+sss;                  //Construct the date and time string
}

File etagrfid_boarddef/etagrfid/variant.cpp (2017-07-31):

/*
  Copyright (c) 2014-2015 Arduino LLC.  All right reserved.

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
  You should have received a copy of the GNU Lesser General Public
  License along with this library; if not, write to the Free Software
  Foundation, Inc., 51 Franklin St, Fifth Floor, Boston, MA  02110-1301  USA
*/
/*
 *
 * + Pin number +  ZERO Board pin  |  PIN   | Label/Name      | Comments (* is for default peripheral in use)
 * +------------+------------------+--------+-----------------+------------------------------
 * |            | Digital Low      |        |                 |
 * +------------+------------------+--------+-----------------+------------------------------
 * | 0          | 0 -> RX          |  PA11  |                 | EIC/EXTINT[11] ADC/AIN[19] PTC/X[3] *SERCOM0/PAD[3] SERCOM2/PAD[3] TCC1/WO[1] TCC0/WO[3]
 * | 1          | 1 <- TX          |  PA10  |                 | EIC/EXTINT[10] ADC/AIN[18] PTC/X[2] *SERCOM0/PAD[2] TCC1/WO[0] TCC0/WO[2]  
 * | 2          | ~2               |  PA08  |                 | EIC/NMI ADC/AIN[16] PTC/X[0] SERCOM0/PAD[0] SERCOM2/PAD[0] *TCC0/WO[0] TCC1/WO[2]
 * | 3          | ~3               |  PA09  |                 | EIC/EXTINT[9] ADC/AIN[17] PTC/X[1] SERCOM0/PAD[1] SERCOM2/PAD[1] *TCC0/WO[1] TCC1/WO[3]
 * | 4          | ~4               |  PA14  |                 | EIC/EXTINT[14] SERCOM2/PAD[2] SERCOM4/PAD[2] TC3/WO[0] *TCC0/WO[4]
 * | 5          | ~5               |  PA15  |                 | EIC/EXTINT[15] SERCOM2/PAD[3] SERCOM4/PAD[3] TC3/WO[1] *TCC0/WO[5]
 * | 6          | ~6               |  PA20  |                 | EIC/EXTINT[4] PTC/X[8] SERCOM5/PAD[2] SERCOM3/PAD[2] TC7/WO[0] *TCC0/WO[6]
 * | 7          | ~7               |  PA21  |                 | EIC/EXTINT[5] PTC/X[9] SERCOM5/PAD[3] SERCOM3/PAD[3] TC7/WO[1] *TCC0/WO[7]
 * +------------+------------------+--------+-----------------+------------------------------
 * |            | Digital High     |        |                 |
 * +------------+------------------+--------+-----------------+------------------------------
 * | 8          | ~8               |  PA06  |                 | EIC/EXTINT[6] PTC/Y[4] ADC/AIN[6] AC/AIN[2] SERCOM0/PAD[2] *TCC1/WO[0]
 * | 9          | ~9               |  PA07  |                 | EIC/EXTINT[7] PTC/Y[5] DC/AIN[7] AC/AIN[3] SERCOM0/PAD[3] *TCC1/WO[1]
 * | 10         | ~10              |  PA18  |                 | EIC/EXTINT[2] PTC/X[6] SERCOM1/PAD[2] SERCOM3/PAD[2] *TC3/WO[0] TCC0/WO[2]
 * | 11         | ~11              |  PA16  |                 | EIC/EXTINT[0] PTC/X[4] SERCOM1/PAD[0] SERCOM3/PAD[0] *TCC2/WO[0] TCC0/WO[6]
 * | 12         | ~12              |  PA19  |                 | EIC/EXTINT[3] PTC/X[7] SERCOM1/PAD[3] SERCOM3/PAD[3] *TC3/WO[1] TCC0/WO[3]
 * | 13         | ~13              |  PA17  | LED             | EIC/EXTINT[1] PTC/X[5] SERCOM1/PAD[1] SERCOM3/PAD[1] *TCC2/WO[1] TCC0/WO[7]
 * | 14         | GND              |        |                 |
 * | 15         | AREF             |  PA03  |                 | *DAC/VREFP PTC/Y[1]
 * | 16         | SDA              |  PA22  |                 | EIC/EXTINT[6] PTC/X[10] *SERCOM3/PAD[0] SERCOM5/PAD[0] TC4/WO[0] TCC0/WO[4]
 * | 17         | SCL              |  PA23  |                 | EIC/EXTINT[7] PTC/X[11] *SERCOM3/PAD[1] SERCOM5/PAD[1] TC4/WO[1] TCC0/WO[5]
 * +------------+------------------+--------+-----------------+------------------------------
 * |            |SPI (Legacy ICSP) |        |                 |
 * +------------+------------------+--------+-----------------+------------------------------
 * | 18         | 1                |  PA12  | MISO            | EIC/EXTINT[12] SERCOM2/PAD[0] *SERCOM4/PAD[0] TCC2/WO[0] TCC0/WO[6]
 * | 19         | 2                |        | 5V0             |
 * | 20         | 3                |  PB11  | SCK             | EIC/EXTINT[11]                *SERCOM4/PAD[3] TC5/WO[1] TCC0/WO[5]
 * | 21         | 4                |  PB10  | MOSI            | EIC/EXTINT[10]                *SERCOM4/PAD[2] TC5/WO[0] TCC0/WO[4]
 * | 22         | 5                |        | RESET           |
 * | 23         | 6                |        | GND             |
 * +------------+------------------+--------+-----------------+------------------------------
 * |            | Analog Connector |        |                 |
 * +------------+------------------+--------+-----------------+------------------------------
 * | 24         | A0               |  PA02  |                 | EIC/EXTINT[2] *ADC/AIN[0] PTC/Y[0] DAC/VOUT
 * | 25         | A1               |  PB08  |                 | EIC/EXTINT[8] *ADC/AIN[2] PTC/Y[14] SERCOM4/PAD[0] TC4/WO[0]
 * | 26         | A2               |  PB09  |                 | EIC/EXTINT[9] *ADC/AIN[3] PTC/Y[15] SERCOM4/PAD[1] TC4/WO[1]
 * | 27         | A3               |  PA04  |                 | EIC/EXTINT[4] *ADC/AIN[4] AC/AIN[0] PTC/Y[2] SERCOM0/PAD[0] TCC0/WO[0]
 * | 28         | A4               |  PA05  |                 | EIC/EXTINT[5] *ADC/AIN[5] AC/AIN[1] PTC/Y[5] SERCOM0/PAD[1] TCC0/WO[1]
 * | 29         | A5               |  PB02  |                 | EIC/EXTINT[2] *ADC/AIN[10] PTC/Y[8] SERCOM5/PAD[0] TC6/WO[0]
 * +------------+------------------+--------+-----------------+------------------------------
 * |            | LEDs             |        |                 |
 * +------------+------------------+--------+-----------------+------------------------------
 * | 30         |                  |  PB03  | RX              |
 * | 31         |                  |  PA27  | TX              |
 * +------------+------------------+--------+-----------------+------------------------------
 * |            | USB              |        |                 |
 * +------------+------------------+--------+-----------------+------------------------------
 * | 32         |                  |  PA28  | USB HOST ENABLE |
 * | 33         |                  |  PA24  | USB_NEGATIVE    | USB/DM
 * | 34         |                  |  PA25  | USB_POSITIVE    | USB/DP
 * +------------+------------------+--------+-----------------+------------------------------
 * |            | EDBG             |        |                 |
 * +------------+------------------+--------+-----------------+------------------------------
 * | 35         |                  |  PB22  | EDBG_UART TX    | SERCOM5/PAD[2]
 * | 36         |                  |  PB23  | EDBG_UART RX    | SERCOM5/PAD[3]
 * +------------+------------------+--------+-----------------+------------------------------
 * | 37         |                  |  PA22  | EDBG_SDA        | SERCOM3/PAD[0]
 * | 38         |                  |  PA23  | EDBG_SCL        | SERCOM3/PAD[1]
 * +------------+------------------+--------+-----------------+------------------------------
 * | 39         |                  |  PA19  | EDBG_MISO       | SERCOM1/PAD[3]
 * | 40         |                  |  PA16  | EDBG_MOSI       | SERCOM1/PAD[0]
 * | 41         |                  |  PA18  | EDBG_SS         | SERCOM1/PAD[2]
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

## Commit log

2017-07-31 Initial commit
    Eagle files and Arduino script for ETAG readers distributed at AOS2017
    [ETAG_v8_u2270b_AOS2017.brd, ETAG_v8_u2270b_AOS2017.sch]
2017-07-31 Added README and board ref
    [arduino_zero.cfg]

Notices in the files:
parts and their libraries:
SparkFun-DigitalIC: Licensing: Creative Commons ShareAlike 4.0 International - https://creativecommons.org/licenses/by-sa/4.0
